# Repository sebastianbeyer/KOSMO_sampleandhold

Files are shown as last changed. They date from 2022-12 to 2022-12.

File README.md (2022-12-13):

Triple Sample and Hold module based on the [Schmitzbits YASH](https://www.schmitzbits.de/sah.html). 
I changed some values to improve the droop rate, because I want to use it to sample CV and not audio.
If nothing is plugged into the inputs, it will sample white noise (should be 6V p2p, but you might tweak 
the values of resistors because it always depends on the transistor (reverse avalanche noise)

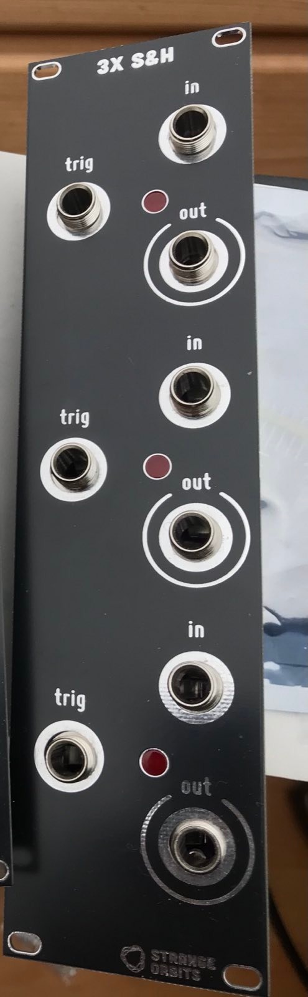
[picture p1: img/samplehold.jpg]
Picture of module


### Videos to show drop rate with different values for the S&H capacitor

https://www.youtube.com/watch?v=smofjtYN6VY

https://www.youtube.com/watch?v=RdAyaS16wt8

https://www.youtube.com/watch?v=JDEQTLfsh5g

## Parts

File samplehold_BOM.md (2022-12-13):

# samplehold.kicad_sch BOM

Tue 13 Dec 2022 10:51:27 CET

Generated from schematic by Eeschema 6.0.8-f2edbf62ab~116~ubuntu22.04.1

**Component Count:** 95

| Refs | Qty | Component | Description | Vendor | SKU |
| ----- | --- | ---- | --- | ---- | ---- |
| C1, C5, C10 | 3 | 470n | Unpolarized capacitor | Tayda |  |
| C2, C6, C9 | 3 | 1.5n | Unpolarized capacitor |  |  |
| C3, C7, C11 | 3 | 1u | Polarized capacitor | Tayda |  |
| C4, C8, C12 | 3 | 100n(PP) | Unpolarized capacitor |  |  |
| C13, C14, C15, C16, C18, C19, C20, C21, C22, C23, C25 | 11 | 100n | Unpolarized capacitor |  |  |
| C17, C24 | 2 | 10u | Polarized capacitor | Tayda |  |
| D1, D3, D5 | 3 | LED_red | Light emitting diode | Tayda | A-1554 |
| D2, D4, D6 | 3 | 1N4148 | Standard switching diode, DO-35 | Tayda | A-157 |
| D7, D8 | 2 | 1N5817 | Schottky Barrier Rectifier Diode, DO-41 | Tayda | A-159 |
| J1 | 1 | in_1 | Audio Jack, 2 Poles (Mono / TS), Switched T Pole (Normalling) | Tayda | A-1121 |
| J2 | 1 | out_1 | Audio Jack, 2 Poles (Mono / TS), Switched T Pole (Normalling) | Tayda | A-1121 |
| J3 | 1 | trig_1 | Audio Jack, 2 Poles (Mono / TS), Switched T Pole (Normalling) | Tayda | A-1121 |
| J4 | 1 | in_2 | Audio Jack, 2 Poles (Mono / TS), Switched T Pole (Normalling) | Tayda | A-1121 |
| J5 | 1 | out_2 | Audio Jack, 2 Poles (Mono / TS), Switched T Pole (Normalling) | Tayda | A-1121 |
| J6 | 1 | trig_2 | Audio Jack, 2 Poles (Mono / TS), Switched T Pole (Normalling) | Tayda | A-1121 |
| J7 | 1 | in_3 | Audio Jack, 2 Poles (Mono / TS), Switched T Pole (Normalling) | Tayda | A-1121 |
| J8 | 1 | out_3 | Audio Jack, 2 Poles (Mono / TS), Switched T Pole (Normalling) | Tayda | A-1121 |
| J9 | 1 | trig_3 | Audio Jack, 2 Poles (Mono / TS), Switched T Pole (Normalling) | Tayda | A-1121 |
| J10 | 1 | Synth_power_2x5 | Pin header 2.54 mm 2x5 | Tayda | A-2939 |
| Q1, Q3, Q4, Q6, Q7, Q9 | 6 | 2N3904 | Small Signal NPN Transistor, TO-92 | Tayda | A-111 |
| Q2, Q5, Q8 | 3 | BC546 | 0.1A Ic, 65V Vce, Small Signal NPN Transistor, TO-92 |  |  |
| R1, R13, R25 | 3 | 2k | Resistor | Tayda |  |
| R2, R9, R14, R21, R26, R33 | 6 | 4.7k | Resistor | Tayda |  |
| R3, R11, R12, R15, R23, R24, R27, R35, R36 | 9 | 100k | Resistor | Tayda |  |
| R4, R16, R30 | 3 | 470k | Resistor | Tayda |  |
| R5, R10, R17, R22, R31, R34 | 6 | 10k | Resistor | Tayda |  |
| R6, R18, R28 | 3 | 5.6k | Resistor | Tayda |  |
| R7, R19, R29 | 3 | 1k | Resistor | Tayda |  |
| R8, R20, R32 | 3 | 1.8k | Resistor | Tayda |  |
| U1, U4, U6 | 3 | HEF4093B | Quad 2-Input NAND Schmitt Trigger, SOIC-14 |  |  |
| U2, U5, U7 | 3 | LF398 | Sample And Hold Unity Gain Follower, DIP-8 |  |  |
| U3 | 1 | TL074 | Quad operational amplifier, DIP-14 | Tayda | A-1138 |

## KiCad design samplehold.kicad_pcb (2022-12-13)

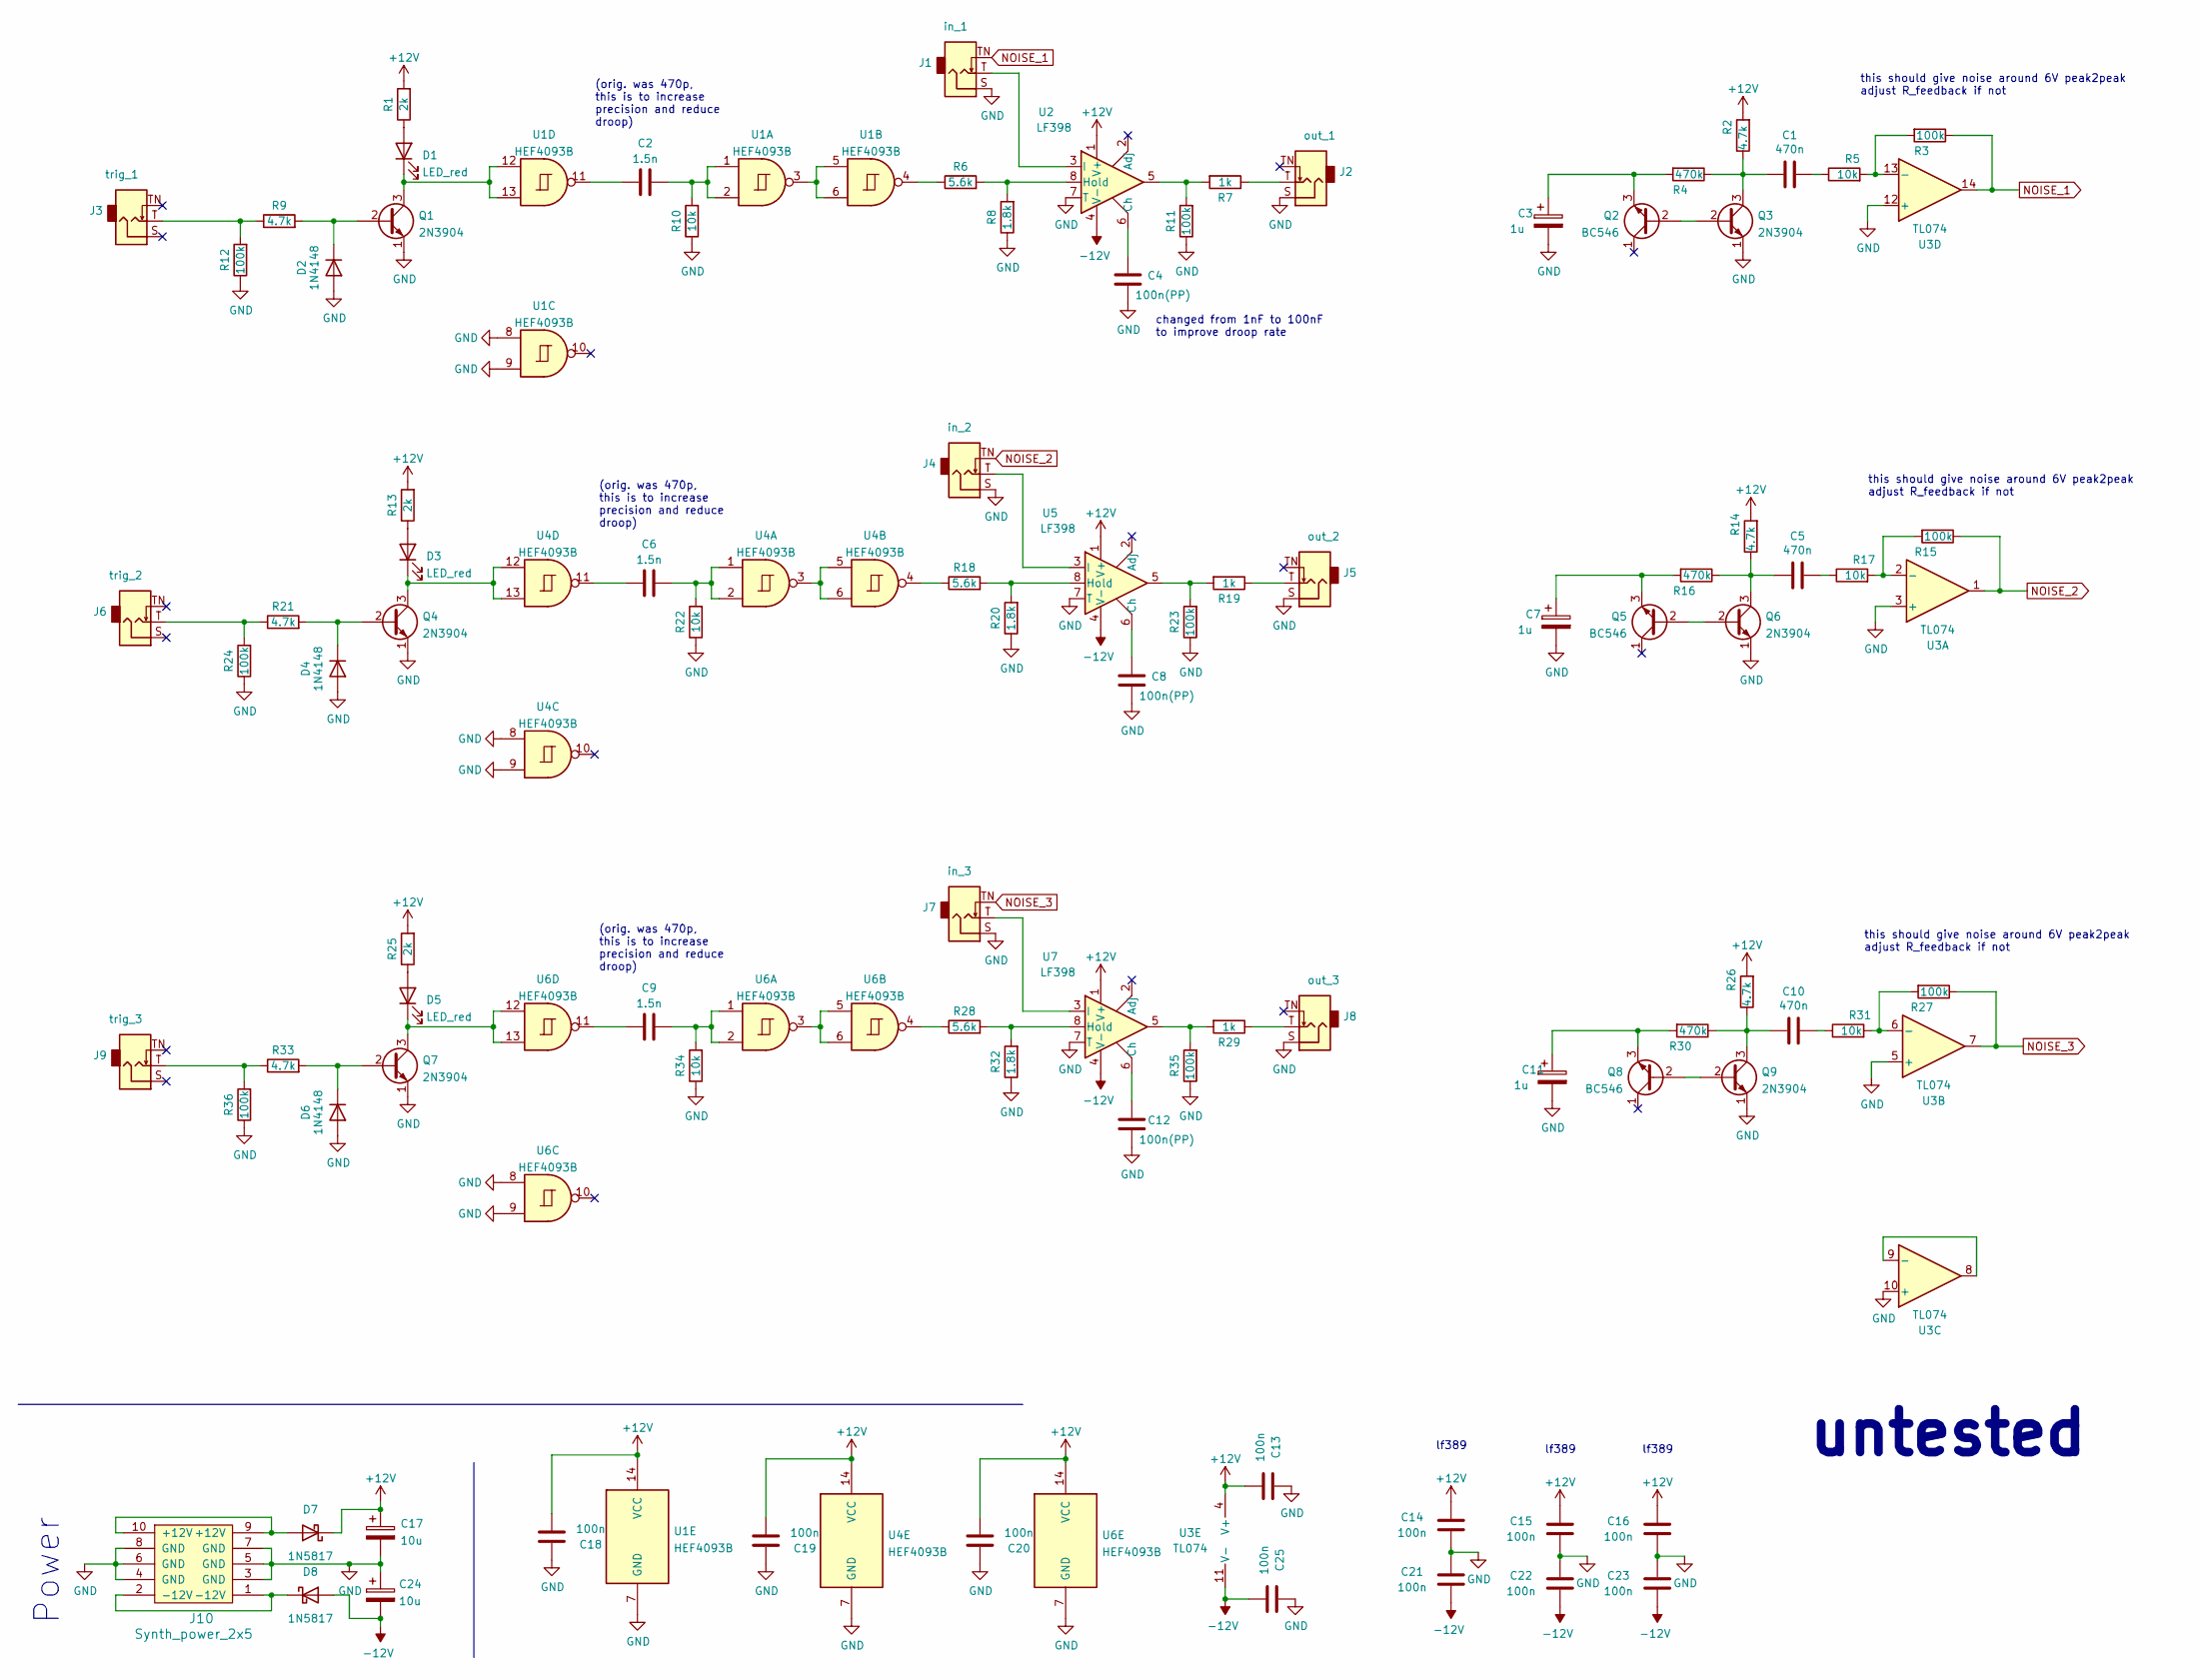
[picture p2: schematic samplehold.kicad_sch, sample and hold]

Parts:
C1, C5, C10: 470n; C_Rect_L7.2mm_W2.5mm_P5.00mm_FKS2_FKP2_MKS2_MKP2
C2, C6, C9: 1.5n; C_Rect_L7.2mm_W2.5mm_P5.00mm_FKS2_FKP2_MKS2_MKP2
C3, C7, C11: 1u; CP_Radial_D5.0mm_P2.00mm
C4, C8, C12: 100n(PP); C_Rect_L7.2mm_W2.5mm_P5.00mm_FKS2_FKP2_MKS2_MKP2
C13, C14, C15, C16, C18, C19, C20, C21, C22, C23, C25: 100n; C_Disc_D3.0mm_W1.6mm_P2.50mm
C17, C24: 10u; CP_Radial_D6.3mm_P2.50mm
D1, D3, D5: LED_red; LED_D5.0mm
D2, D4, D6: 1N4148; D_DO-35_SOD27_P7.62mm_Horizontal
D7, D8: 1N5817; D_DO-41_SOD81_P7.62mm_Horizontal
J1: in_1; Jack_6.35mm_PJ_629HAN
J2: out_1; Jack_6.35mm_PJ_629HAN
J3: trig_1; Jack_6.35mm_PJ_629HAN
J4: in_2; Jack_6.35mm_PJ_629HAN
J5: out_2; Jack_6.35mm_PJ_629HAN
J6: trig_2; Jack_6.35mm_PJ_629HAN
J7: in_3; Jack_6.35mm_PJ_629HAN
J8: out_3; Jack_6.35mm_PJ_629HAN
J9: trig_3; Jack_6.35mm_PJ_629HAN
J10: Synth_power_2x5; Power_Header
Q1, Q3, Q4, Q6, Q7, Q9: 2N3904; TO-92_Inline_Wide
Q2, Q5, Q8: BC546; TO-92_Inline_Wide
R1, R13, R25: 2k; R_Axial_DIN0207_L6.3mm_D2.5mm_P2.54mm_Vertical
R2, R9, R14, R21, R26, R33: 4.7k; R_Axial_DIN0207_L6.3mm_D2.5mm_P2.54mm_Vertical
R3, R11, R12, R15, R23, R24, R27, R35, R36: 100k; R_Axial_DIN0207_L6.3mm_D2.5mm_P2.54mm_Vertical
R4, R16, R30: 470k; R_Axial_DIN0207_L6.3mm_D2.5mm_P2.54mm_Vertical
R5, R10, R17, R22, R31, R34: 10k; R_Axial_DIN0207_L6.3mm_D2.5mm_P2.54mm_Vertical
R6, R18, R28: 5.6k; R_Axial_DIN0207_L6.3mm_D2.5mm_P2.54mm_Vertical
R7, R19, R29: 1k; R_Axial_DIN0207_L6.3mm_D2.5mm_P2.54mm_Vertical
R8, R20, R32: 1.8k; R_Axial_DIN0207_L6.3mm_D2.5mm_P2.54mm_Vertical
U1, U4, U6: HEF4093B; DIP-14_W7.62mm_Socket_LongPads
U2, U5, U7: LF398; DIP-8_W7.62mm_Socket_LongPads
U3: TL074; DIP-14_W7.62mm_Socket_LongPads

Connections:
+12V: C13.2, C14.1, C15.1, C16.1, C17.1, C18.2, C19.2, C20.2, D7.1 (K), R1.2, R2.2, R13.2, R14.2, R25.2, R26.2, U1.14 (VCC), U2.1 (V+), U3.4 (V+), U4.14 (VCC), U5.1 (V+), U6.14 (VCC), U7.1 (V+)
-12V: C21.2, C22.2, C23.2, C24.2, C25.2, D8.2 (A), U2.4 (V-), U3.11 (V-), U5.4 (V-), U7.4 (V-)
GND: C3.2, C4.1, C7.2, C8.1, C11.2, C12.1, C13.1, C14.2, C15.2, C16.2, C17.2, C18.1, C19.1, C20.1, C21.1, C22.1, C23.1, C24.1, C25.1, D2.2 (A), D4.2 (A), D6.2 (A), J1.S, J2.S, J4.S, J5.S, J7.S, J8.S, J10.3 (GND), J10.4 (GND), J10.5 (GND), J10.6 (GND), J10.7 (GND), J10.8 (GND), Q1.1 (E), Q3.1 (E), Q4.1 (E), Q6.1 (E), Q7.1 (E), Q9.1 (E), R8.1, R10.1, R11.1, R12.1, R20.1, R22.1, R23.1, R24.1, R32.1, R34.1, R35.1, R36.1, U1.7 (GND), U1.8, U1.9, U2.7 (T), U3.3 (+), U3.5 (+), U3.10 (+), U3.12 (+), U4.7 (GND), U4.8, U4.9, U5.7 (T), U6.7 (GND), U6.8, U6.9, U7.7 (T)
NOISE_1: J1.TN, R3.1, U3.14
NOISE_2: J4.TN, R15.1, U3.1
NOISE_3: J7.TN, R27.1, U3.7
unnamed: C1.1, R5.1
unnamed: C1.2, Q3.3 (C), R2.1, R4.1
unnamed: C2.1, R10.2, U1.1, U1.2
unnamed: C2.2, U1.11
unnamed: C3.1, Q2.3 (E), R4.2
unnamed: C4.2, U2.6 (Ch)
unnamed: C5.1, R17.1
unnamed: C5.2, Q6.3 (C), R14.1, R16.1
unnamed: C6.1, R22.2, U4.1, U4.2
unnamed: C6.2, U4.11
unnamed: C7.1, Q5.3 (E), R16.2
unnamed: C8.2, U5.6 (Ch)
unnamed: C9.1, R34.2, U6.1, U6.2
unnamed: C9.2, U6.11
unnamed: C10.1, R31.1
unnamed: C10.2, Q9.3 (C), R26.1, R30.1
unnamed: C11.1, Q8.3 (E), R30.2
unnamed: C12.2, U7.6 (Ch)
unnamed: D1.1 (K), Q1.3 (C), U1.12, U1.13
unnamed: D1.2 (A), R1.1
unnamed: D2.1 (K), Q1.2 (B), R9.2
unnamed: D3.1 (K), Q4.3 (C), U4.12, U4.13
unnamed: D3.2 (A), R13.1
unnamed: D4.1 (K), Q4.2 (B), R21.2
unnamed: D5.1 (K), Q7.3 (C), U6.12, U6.13
unnamed: D5.2 (A), R25.1
unnamed: D6.1 (K), Q7.2 (B), R33.2
unnamed: D7.2 (A), J10.9 (+12V), J10.10 (+12V)
unnamed: D8.1 (K), J10.1 (-12V), J10.2 (-12V)
unnamed: J1.T, U2.3 (I)
unnamed: J2.T, R7.1
unnamed: J3.T, R9.1, R12.2
unnamed: J4.T, U5.3 (I)
unnamed: J5.T, R19.1
unnamed: J6.T, R21.1, R24.2
unnamed: J7.T, U7.3 (I)
unnamed: J8.T, R29.1
unnamed: J9.T, R33.1, R36.2
unnamed: Q2.2 (B), Q3.2 (B)
unnamed: Q5.2 (B), Q6.2 (B)
unnamed: Q8.2 (B), Q9.2 (B)
unnamed: R3.2, R5.2, U3.13 (-)
unnamed: R6.1, U1.4
unnamed: R6.2, R8.2, U2.8 (Hold)
unnamed: R7.2, R11.2, U2.5
unnamed: R15.2, R17.2, U3.2 (-)
unnamed: R18.1, U4.4
unnamed: R18.2, R20.2, U5.8 (Hold)
unnamed: R19.2, R23.2, U5.5
unnamed: R27.2, R31.2, U3.6 (-)
unnamed: R28.1, U6.4
unnamed: R28.2, R32.2, U7.8 (Hold)
unnamed: R29.2, R35.2, U7.5
unnamed: U1.3, U1.5, U1.6
unnamed: U3.8, U3.9 (-)
unnamed: U4.3, U4.5, U4.6
unnamed: U6.3, U6.5, U6.6

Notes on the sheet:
this should give noise around 6V peak2peak adjust R_feedback if not
untested
lf389
changed from 1nF to 100nF to improve droop rate
Power
(orig. was 470p, this is to increase precision and reduce droop)

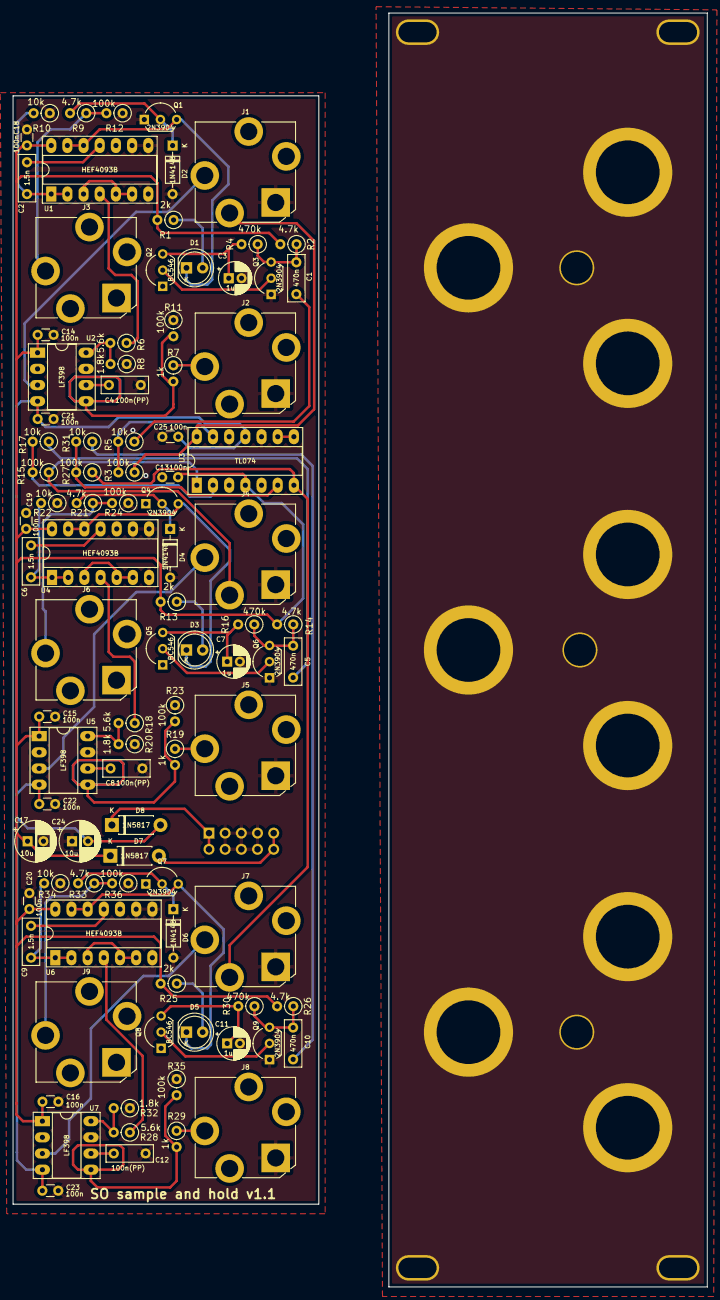
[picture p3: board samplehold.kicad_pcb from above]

Board: 2 copper layers, 48.0 x 174.0 mm, 95 parts (1 on the bottom side), 63 nets.
